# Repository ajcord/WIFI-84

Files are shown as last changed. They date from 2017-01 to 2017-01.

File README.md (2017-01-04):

# WIFI-84
*Wi-Fi Interface Furnishing Internet for TI-84*

## Overview

This project aims to provide direct Internet access to TI-84 calculators
using an inexpensive ESP8266 module as a wireless modem.
It supports calculators with I/O ports, i.e. those up to the TI-84+CSE.

## Architecture

The project consists of four main parts:

1. A physical interface between the calculator and ESP8266
2. A driver for communicating between them
3. A high-level networking API exposed to calculator programs
4. A small collection of sample utilities using the API

### Physical interface

The adapter is powered from the calculator's USB port for convenience.
It could probably also be powered from e.g. a USB phone charger,
as long as the power supply is not noisy.
The USB's 5V gets converted to 3.3V using an efficient switching regulator
to save battery.

For communication, the adapter uses the I/O port for simplicity.
Ideally, it would use the USB port for forward compatibility and since
it already uses it for power;
however, writing a USB driver would be a lot of effort for very little gain,
considering that the TI-84+CE uses a completely different USB controller.

It would be nice to have the adapter plug directly into the calculator,
but I can't seem to find any 2.5mm male headphone connectors,
and the only USB mini-B male connector I found is vertical.
Instead, the adapter plugs in using cables,
but is laid out to make it easy to switch to a plug-oriented design later.
See the `hardware` folder for the schematic and circuit board.

### Driver

The ESP8266 runs firmware that directly communicates with the calculator
using the [ArTICL](https://github.com/KermMartian/ArTICL) library.
It acts as a CBL2 device to make communication easy with TI Basic programs.

The calculator does not need a driver since it uses the CBL2
Get( and Send( commands.
It does, however, need a way to turn on and off the USB port.

### API

The API exposed to the calculator is still in flux,
but it will provide similar capabilities to the ESP8266's default AT firmware.
The calculator will be able to send string variables containing API calls,
and then it will request another variable to get the result (if applicable).

The calculator will send token strings as commands
in order to save program space.
The ESP8266 will respond with token strings or real numbers,
depending on the call.

### Utilities

There will need to be a program to allow the user to connect to
nearby Wi-Fi networks.
It can be as simple as a menu of SSIDs.
By including such a program, applications won't need to
reinvent the wheel, and the connection can be managed centrally.

Also, a tool like wget/curl would be useful for testing.
It would probably have to include its own viewer to display the response
incrementally due to limited RAM.
For HTML, maybe it could have the option to display it with tags stripped
so that it looks sort of like a webpage.

In the future, it would be really cool to have the ESP8266 pre-render webpages
and have the calculator display them screen by screen.
A Slack client would also be neat.

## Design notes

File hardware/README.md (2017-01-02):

# Hardware

## Schematic

See `wifi-adapter.sch` for the schematic,
or `wifi-adapter.pdf` if you don't have EAGLE.

## Bill of Materials

This DigiKey cart contains all the components needed in the project:
[cart](http://www.digikey.com/short/3r35nm)

In addition, you will need to manufacture a circuit board using
`wifi-adapter.brd`.
[OSH Park](https://oshpark.com) is a good place to order it.

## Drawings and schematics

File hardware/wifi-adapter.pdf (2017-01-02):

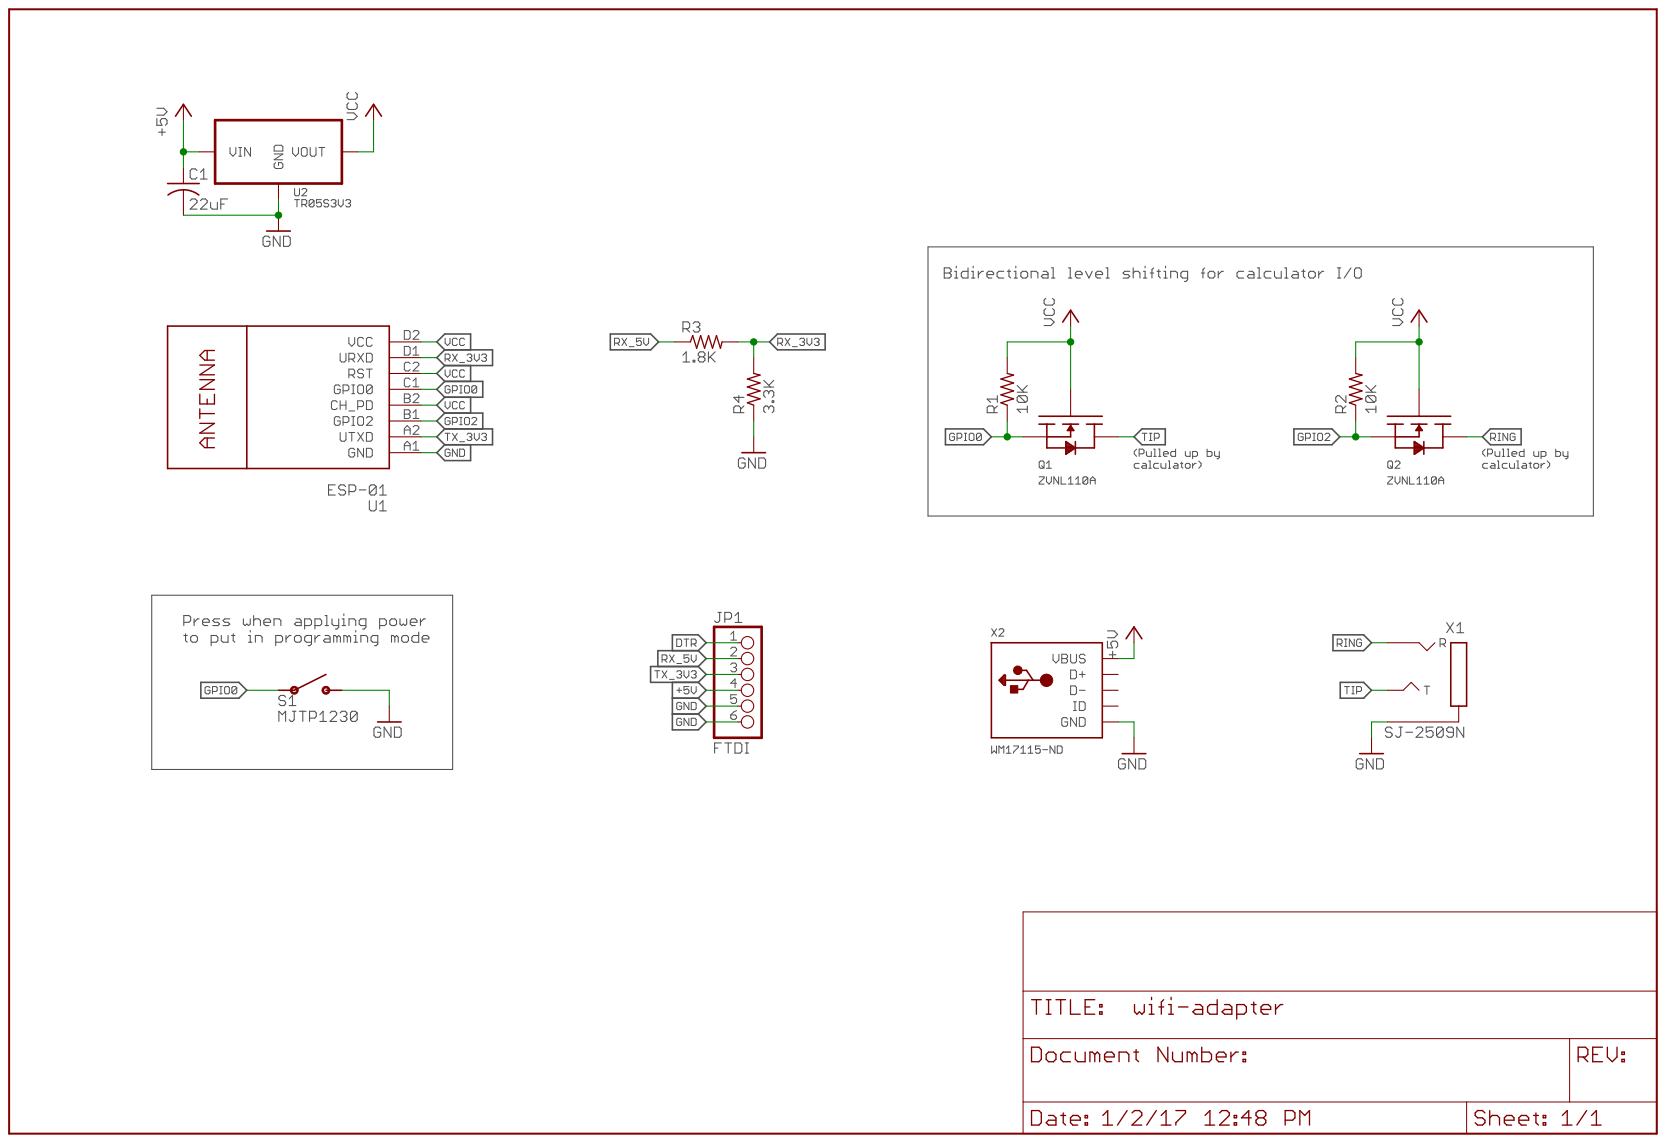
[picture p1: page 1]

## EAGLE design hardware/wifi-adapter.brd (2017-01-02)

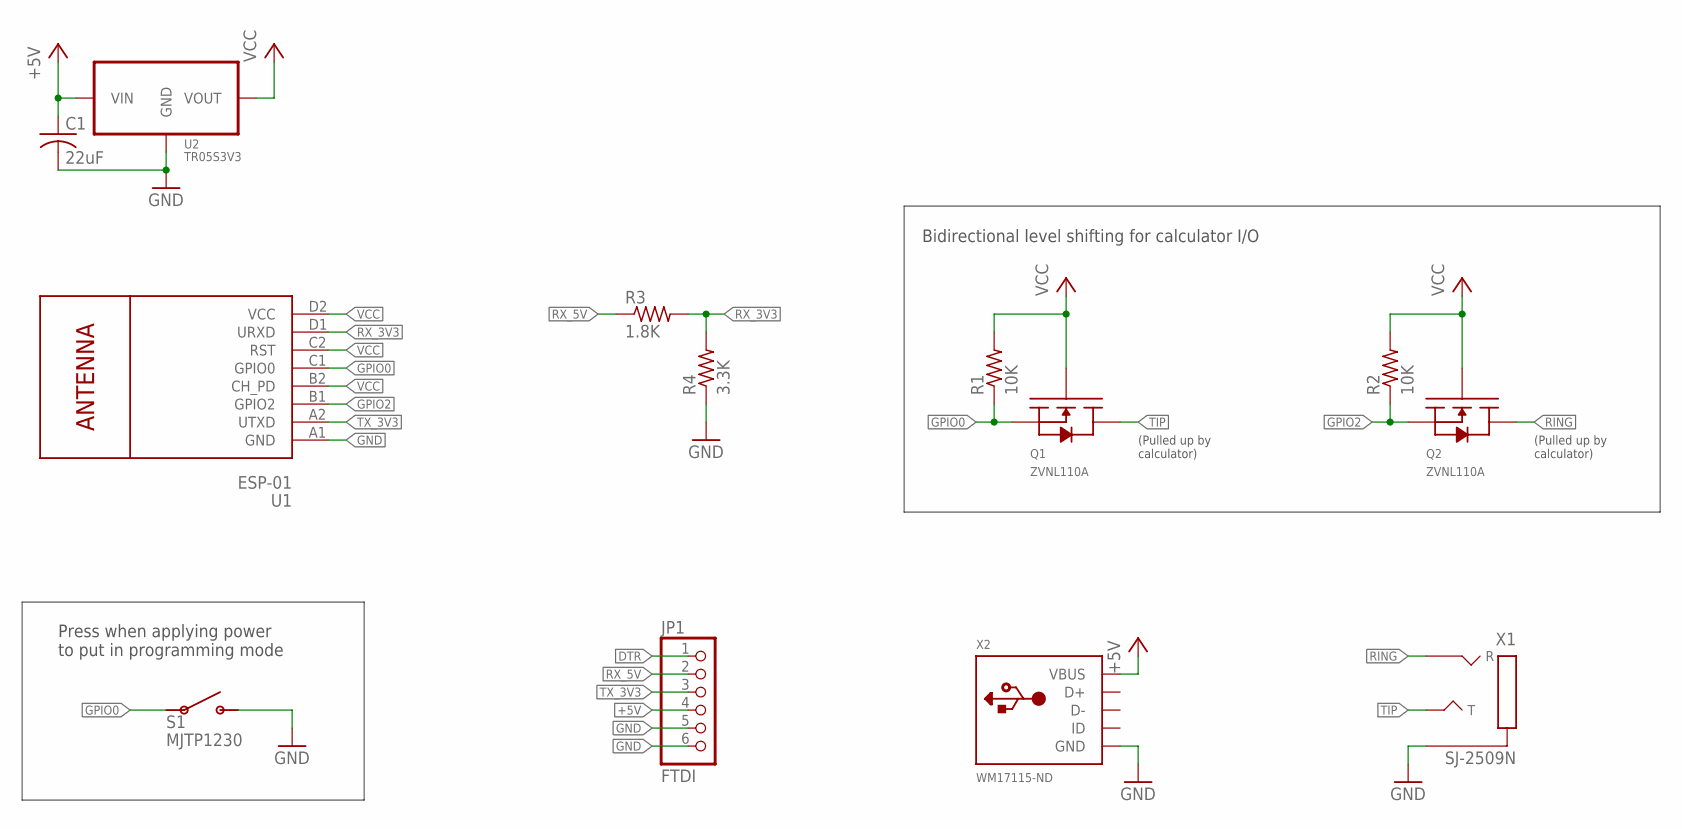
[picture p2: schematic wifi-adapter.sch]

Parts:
C1: 22uF; C025-025X050
JP1: FTDI; 1X06
Q1, Q2: ZVNL110A; E-LINE-RA
R1, R2: 10K; 0207/10
R3: 1.8K; 0207/10
R4: 3.3K; 0207/10
S1: MJTP1230; TACTILE-BUTTON-MJTP1230
U1: ESP-01; WIRELESS-WIFI-ESP-01
U2: TR05S3V3; 3-SIP
X1: SJ-2509N
X2: WM17115-ND; USB-MINI-B

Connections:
+5V: C1.1, JP1.4, U2.P$1 (VIN), X2.VBUS
DTR: JP1.1
GND: C1.2, JP1.5, JP1.6, R4.1, S1.P$2 (3), S1.P$4 (3), U1.A1 (GND), U2.P$2 (GND), X1.P$1, X2.GND, X2.GND1 (GND), X2.GND4 (GND)
GPIO0: Q1.P$3 (S), R1.1, S1.P$1 (1), S1.P$3 (1), U1.C1 (GPIO0)
GPIO2: Q2.P$3 (S), R2.1, U1.B1 (GPIO2)
RING: Q2.P$1 (D), X1.P$2
RX_3V3: R3.2, R4.2, U1.D1 (URXD)
RX_5V: JP1.2, R3.1
TIP: Q1.P$1 (D), X1.P$3
TX_3V3: JP1.3, U1.A2 (UTXD)
VCC: Q1.P$2 (G), Q2.P$2 (G), R1.2, R2.2, U1.B2 (CH_PD), U1.C2 (RST), U1.D2 (VCC), U2.P$3 (VOUT)

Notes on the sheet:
(Pulled up by calculator)
Bidirectional level shifting for calculator I/O
Press when applying power to put in programming mode

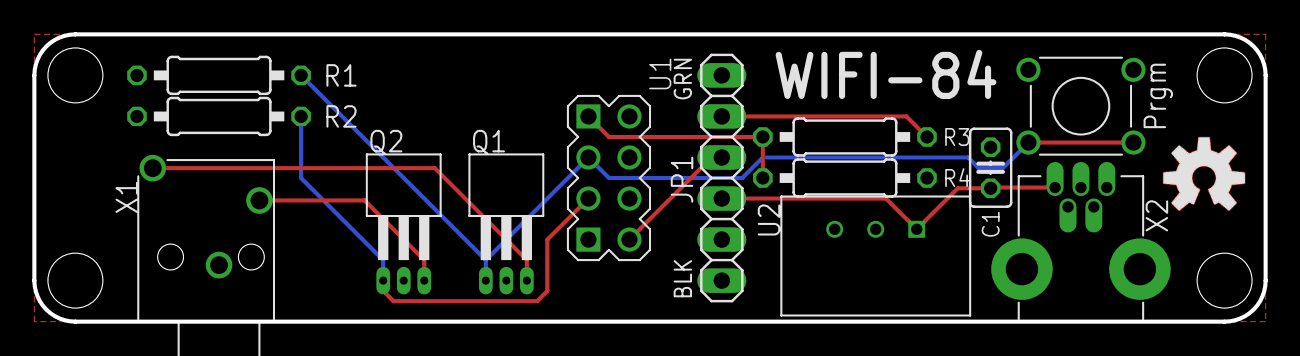
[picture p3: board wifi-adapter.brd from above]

Board: 2 copper layers, 76.2 x 17.8 mm, 15 parts (0 on the bottom side), 10 nets.

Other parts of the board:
U$1: OSHW-LOGO-M
U$2: OSHW-LOGO-M_COPPER

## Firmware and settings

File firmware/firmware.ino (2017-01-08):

#include <ESP8266WiFi.h>
#include <WiFiUdp.h>
#include <ESP8266HTTPClient.h>
#include <CBL2.h>
#include <TIVar.h>
#include "TokenParser.h"
#include "Tokens.h"

CBL2 cbl;

const int tipPin = 0;
const int ringPin = 2;

const int maxDataLen = 512;
uint8_t header[16];
uint8_t data[maxDataLen];

String pendingString;
long pendingReal;

WiFiClient tcpClient;
WiFiUDP udpClient;

// For artificial UDP connection management
bool isUDP;
String udpAddr;
uint16_t udpPort;

void setup() {
    Serial.begin(115200);
    cbl.setLines(tipPin, ringPin);
    cbl.resetLines();
    cbl.setupCallbacks(header, data, maxDataLen, onReceived, onRequest);
    Serial.println("Ready");
}

void loop() {
    cbl.eventLoopTick();
}

// Called when a variable is received from the calculator
int onReceived(uint8_t type, enum Endpoint model, int datalen) {
    Serial.println("Received variable of type " + type);
    if (type != VarTypes82::VarString) {
        // Require strings only
        Serial.println("Rejected");
        return -1;
    }

    String params = TIVar::strVarToString8x(data, model);
    if (params.endsWith(")")) {
        params = params.substring(1, params.length() - 1);
    } else {
        params = params.substring(1);
    }

    TokenParser parser(&data[2]);
    Token::Token tok = parser.nextToken();
    switch (tok) {
        /**
         * Get Wi-Fi connection status.
         * 
         * Syntax: Connected
         * 
         * Returns one of the following real values in A:
         * - 0 if connected
         * - 1 if disconnected
         * - 2 if SSID cannot be reached
         * - 3 if password is incorrect
         * - 4 if in between states
         * Returns the currently connected SSID, if any, in Str1.
         */
        case Token::Connected: {
            pendingReal = -1;
            switch (WiFi.status()) {
                case WL_CONNECTED:      pendingReal = 0; break;
                case WL_DISCONNECTED:   pendingReal = 1; break;
                case WL_NO_SSID_AVAIL:  pendingReal = 2; break;
                case WL_CONNECT_FAILED: pendingReal = 3; break;
                case WL_IDLE_STATUS:    pendingReal = 4; break;
            }
            pendingString = WiFi.SSID();
            Serial.println("Connected to: " + pendingString);
            Serial.println("Connection status: " + pendingReal);
            break;
        }

        /**
         * Get a list of nearby access points.
         * 
         * Syntax: Menu()
         * 
         * Returns a CSV of access points in Str1, in the following format:
         * ssid1,encryption1,rssi1/ssid2,encryption2,rssi2/...
         * - ssid is the name of the network
         * - encryption is an integer enumeration of various security types:
         *   - 0 = open
         *   - 1 = WEP
         *   - 2 = WPA
         *   - 3 = WPA2
         *   - 4 = WPA/WPA2 mixed
         * - rssi is the signal strength in dBm
         */
        case Token::Menu: {
            int num = WiFi.scanNetworks();
            pendingString = "";
            for (int i = 0; i < num; i++) {
                int encryption = -1;
                switch (WiFi.encryptionType(i)) {
                    case ENC_TYPE_NONE: encryption = 0; break;
                    case ENC_TYPE_WEP:  encryption = 1; break;
                    case ENC_TYPE_TKIP: encryption = 2; break; // WPA
                    case ENC_TYPE_CCMP: encryption = 3; break; // WPA2
                    case ENC_TYPE_AUTO: encryption = 4; break; // WPA/WPA2
                }
                pendingString.concat(
                    WiFi.SSID(i) + ',' + encryption + ',' + WiFi.RSSI(i) + '/'
                );
            }
            Serial.println("AP list: " + pendingString);
            break;
        }

        /**
         * Connect to an access point.
         * 
         * Syntax: Select(ssid)
         * Alternate: Select(ssid,password)
         * 
         * Returns nothing. Use "Connected" to get the result.
         */
        case Token::Select: {
            int commaIndex = params.indexOf(",");
            if (commaIndex != -1) {
                String ssid = params.substring(0, commaIndex);
                String pass = params.substring(commaIndex + 1);
                WiFi.begin(ssid.c_str(), pass.c_str());
                Serial.println("Connecting to \"" + ssid + "\"");
            } else {
                WiFi.begin(params.c_str());
                Serial.println("Connecting to \"" + params + "\"");
            }
            break;
        }

        /**
         * Connect to a TCP or UDP server.
         * 
         * Syntax: For(type,addr,port)
         * Where:
         * - type = 0 for UDP, 1 for TCP
         * - addr = remote IP address or hostname
         * - port = remote port
         * 
         * Returns A = 1 on success or 0 on failure.
         * Note that UDP connections are artificial and always succeed unless
         * no sockets are available.
         * 
         * TODO: eventually would like to support multiple connections,
         * like sockets. Shouldn't be that bad with an array of WiFiClients
         * and a Berkeley-style interface.
         */
        case Token::For: {
            int firstCommaIndex = params.indexOf(",");
            int lastCommaIndex = params.lastIndexOf(",");
            if (firstCommaIndex == lastCommaIndex) {
                break;
            }
            int type = params.substring(0, firstCommaIndex).toInt();
            String addr = params.substring(firstCommaIndex + 1, lastCommaIndex);
            uint16_t port = params.substring(lastCommaIndex + 1).toInt();
            if (type) {
                isUDP = false;
                pendingReal = tcpClient.connect(addr.c_str(), port);
                Serial.println("Connecting via TCP to " + addr + ":" + port);
            } else {
                udpAddr = addr;
                udpPort = port;
                // For simplicity, use the remote port as the local port too
                pendingReal = udpClient.begin(port);
                isUDP = pendingReal;
                Serial.println("Connecting via UDP to " + addr + ":" + port);
            }
        }

        /**
         * Close the current connection.
         * 
         * Syntax: Stop
         * 
         * Returns nothing.
         */
        case Token::Stop: {
            if (isUDP) {
                udpClient.stop();
            } else {
                tcpClient.stop();
            }
            Serial.println("Connection closed");
        }

        /**
         * Transmit data over the current connection.
         * 
         * Syntax: DS<(data)
         * Where data is the text to send.
         * 
         * Returns nothing.
         */
        case Token::DS: {
            if (isUDP) {
                udpClient.beginPacket(udpAddr.c_str(), udpPort);
                udpClient.write(params.c_str(), params.length());
                udpClient.endPacket();
            } else {
                tcpClient.print(params);
            }
            Serial.println("Sending: " + params);
        }

        /**
         * Receive data from the current connection.
         * 
         * Syntax: IS>()
         * 
         * Returns the data received, if any, in Str1.
         */
         case Token::IS: {
            if (isUDP) {
                int len = udpClient.parsePacket();
                uint8_t* buf = (uint8_t*)malloc(len + 1);
                udpClient.read(buf, len);
                buf[len] = '\0';
                pendingString = String((const char*)buf);
                free(buf);
            } else {
                pendingString = "";
                while (tcpClient.available()) {
                    pendingString.concat(tcpClient.read());
                }
            }
            Serial.println("Received: " + pendingString);
         }

         /**
          * Gets a URL via HTTP.
          * 
          * Syntax: Get(url)
          * 
          * Returns the response in Str1 and the HTTP code in A.
          * A will be negative if there was an error in sending the request.
          */
         case Token::Get: {
            HTTPClient http;
            http.begin(params);
            Serial.println("Requesting " + params);
            pendingReal = http.GET();
            if (pendingReal > 0) {
                pendingString = http.getString();
            } else {
                pendingString = "";
            }
            Serial.println("HTTP code: " + pendingReal);
            Serial.println("Response: " + pendingString);
         }

         /**
          * Posts to a URL via HTTP.
          * 
          * Syntax: Send(url,payload)
          * 
          * Returns the response in Str1 and the HTTP code in A.
          * A will be negative if there was an error in sending the request.
          */
         case Token::Send: {
            HTTPClient http;
            int commaIndex = params.indexOf(",");
            String url = params.substring(0, commaIndex);
            String payload = params.substring(commaIndex + 1);
            http.begin(url);
            Serial.println("Posting \"" + payload + "\" to " + url);
            pendingReal = http.POST((uint8_t*)payload.c_str(), payload.length());
            if (pendingReal > 0) {
                pendingString = http.getString();
            } else {
                pendingString = "";
            }
            Serial.println("HTTP code: " + pendingReal);
            Serial.println("Response: " + pendingString);
         }
    }
    return 0;
}

// Called when the calculator requests a variable
int onRequest(uint8_t type, enum Endpoint model, int* headerlen, int* datalen,
              data_callback* data_callback) {
    Serial.println("Got request for variable of type " + type);
    switch(type) {
        case VarTypes82::VarString: {
            int rval = TIVar::stringToStrVar8x(pendingString, data, model);
            if (rval < 0) {
                return -1;
            }
            *datalen = rval;

            memset(header, 0, sizeof(header));
            TIVar::intToSizeWord(rval, header);
            header[2] = type; // Variable type
            header[3] = 0xAA; // Variable name (Str1)
            header[4] = 0x00; // ^
            *headerlen = 13;
            Serial.println("Responding with \"" + pendingString + "\"");
            return 0;
        }
        case VarTypes82::VarReal: {
            int rval = TIVar::longToReal8x(pendingReal, data, model);
            if (rval < 0) {
                return -1;
            }
            *datalen = rval;

            memset(header, 0, sizeof(header));
            TIVar::intToSizeWord(rval, header);
            header[2] = type; // Variable type
            header[3] = 0x41; // Variable name (A)
            *headerlen = 13;
            Serial.println("Responding with " + pendingReal);
            return 0;
        }
        default:
            *headerlen = 0;
            *datalen = 0;
            Serial.println("Rejected");
            return -1;
    }
}

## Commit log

2017-01-02 First real commit
    [wifi-adapter.brd, wifi-adapter.sch]
2017-01-03 Fixed Connected to return 1 or 0, not enum
    [firmware.ino]
2017-01-03 Rename insert() to append() for clarity
2017-01-03 Compacted case statements
2017-01-03 Switched to unsigned chars
2017-01-03 Fixed a couple of character conversion mistakes
2017-01-04 Added some debug printing
2017-01-04 Switched tokens for sending/receiving on a connection
2017-01-06 Added timeout, default to current network, and fixed syntax errors

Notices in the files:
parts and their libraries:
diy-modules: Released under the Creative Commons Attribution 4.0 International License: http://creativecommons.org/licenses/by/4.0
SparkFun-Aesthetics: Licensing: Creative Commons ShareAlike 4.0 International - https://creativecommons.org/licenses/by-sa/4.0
